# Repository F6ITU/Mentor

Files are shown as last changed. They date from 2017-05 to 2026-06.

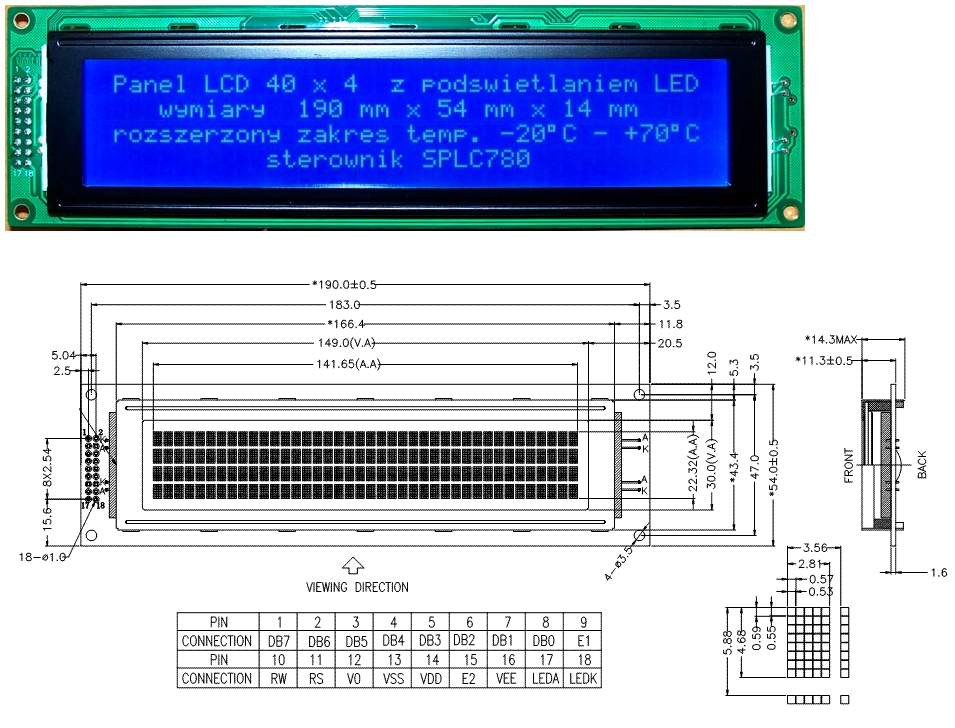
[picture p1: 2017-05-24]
Datasheet/4x40 display pinout.PNG

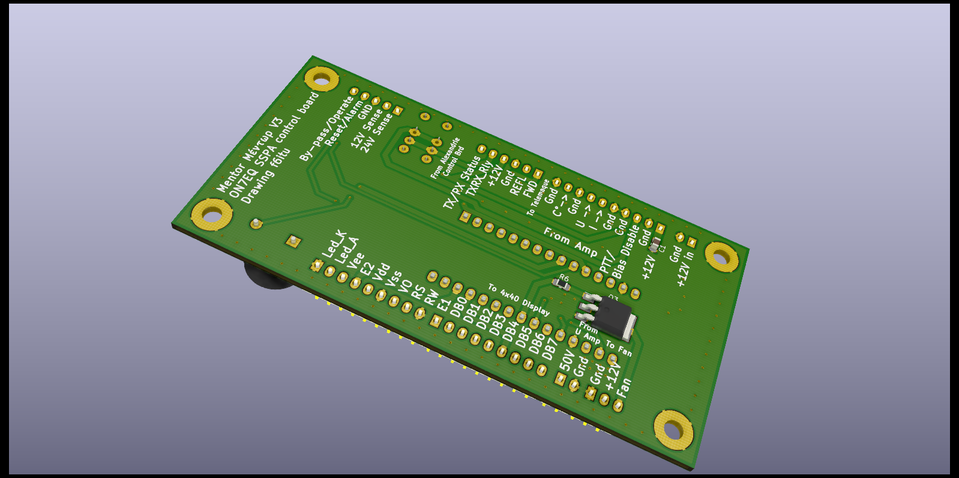
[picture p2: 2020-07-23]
pictures/Mentor_Dwh.png

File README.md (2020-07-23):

# Mentor

Kicad files

An Arduino based SSPA display controler for HPSDR/Hermes familly
This module controls 
- voltage
- current
- temperature
- VSWR/PWR
- cooling fan
- 4x40 lcd display
and shuts down the Bias current while beeping in case of dificulties

This board and the associated firmware have been developped by ON7EQ. 

http://www.qsl.net/on7eq/projects/arduino_sspa.htm

Some code modifications have been made by John Melton for 
the Hermes familly.

The design of this board uses the generic output names
used by all Hermes/Angelia boards and could directly be plugged 
on the Alexandrie control board

So far, NO SSPA and NO Reflectometer/Refl-fwd coupler have been
designed. A multipurpose 33dB Tandem Match coupler
is under development (for both VSWR/PWR measurement and 
predistorsion -aka "pure signal"- sampling)

Board's dimensions are oversized to fit the 5x10 and 10x10cm 
size of all board of the Hermes project under Kicad: 

AlexI2C

Alexandrie 

Alexiares_Coax_Out

Alexiares_HPF

Alexiares_LPF

Mentor(this one)

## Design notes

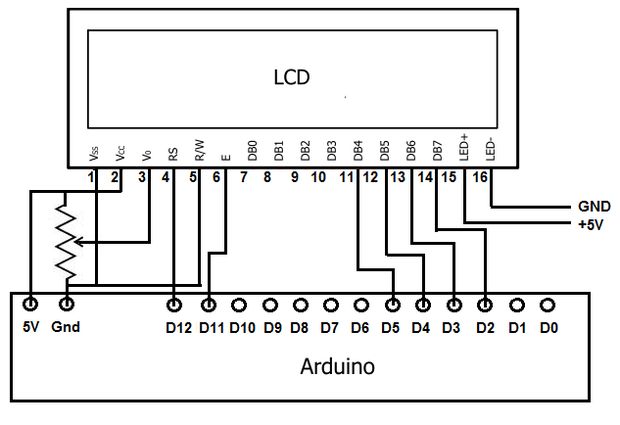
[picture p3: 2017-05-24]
Datasheet/lcd pinout.jpg

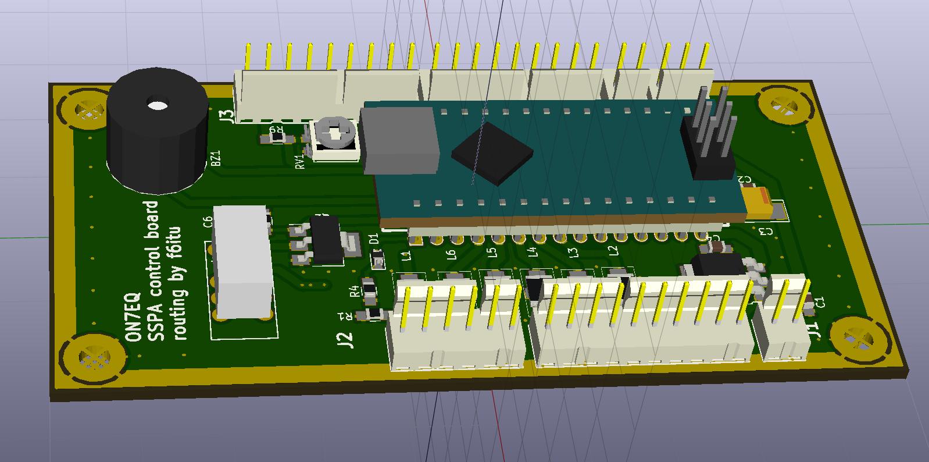
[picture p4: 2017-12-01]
Mentor_up.jpg

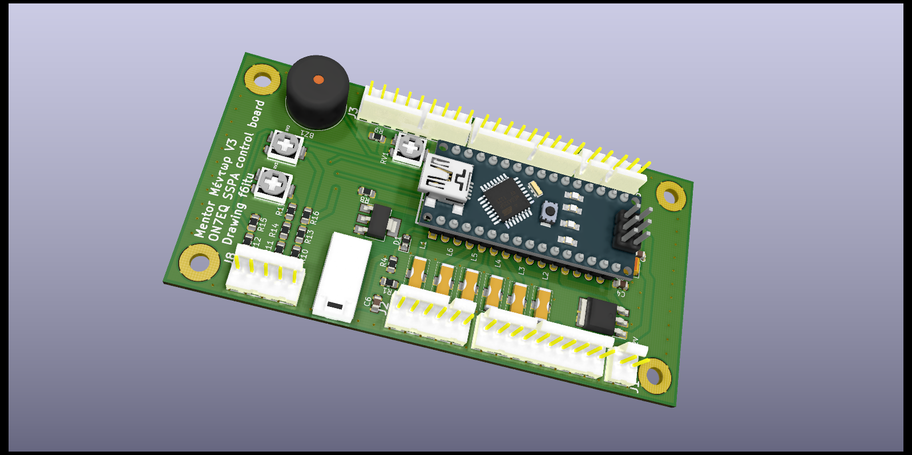
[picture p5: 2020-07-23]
pictures/Mentor_Up.png

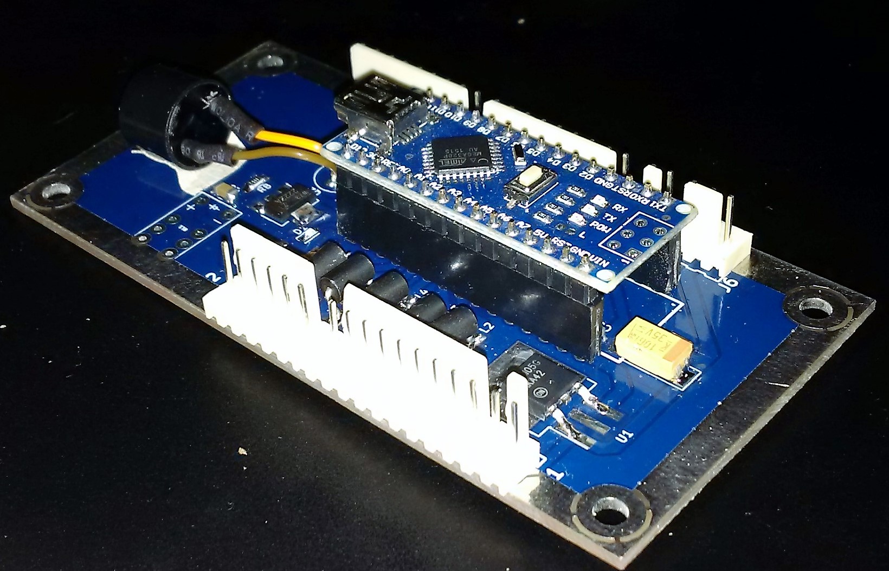
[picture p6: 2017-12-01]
Mentor_pcb.jpg

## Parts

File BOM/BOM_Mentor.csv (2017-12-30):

Component Count: | 37
Ref | Value | Footprint | Datasheet | Manufacturer | Vendor
BZ1 | Buzzer | Buzzers_Beepers:Buzzer_12x9.5RM7.6
C1 | 100n | Capacitors_SMD:C_0805_HandSoldering
C2 | 10u | Capacitors_Tantalum_SMD:CP_Tantalum_Case-C_EIA-6032-28_Hand
C3 | 100n | Capacitors_SMD:C_0805_HandSoldering
C4 | 100n | Capacitors_SMD:C_0805_HandSoldering
C5 | 100n | Capacitors_SMD:C_0805_HandSoldering
C6 | 100n | Capacitors_SMD:C_0805_HandSoldering
D1 | LED | Diodes_SMD:D_0805 | LED
J1 | CONN_01X02 | conn_kk100:kk100_22-23-2021
J2 | CONN_01X06 | conn_kk100:kk100_22-23-2061
J3 | CONN_01X09 | conn_kk100:kk100_22-23-2091
J4 | CONN_01X10 | conn_kk100:kk100_22-23-2101
J5 | CONN_01X02 | conn_kk100:kk100_22-23-2021
J6 | CONN_01X03 | conn_kk100:kk100_22-23-2031
J7 | CONN_01X09 | conn_kk100:kk100_22-23-2091
L1 | L_cap | Ferrite_LC_NFM41P:Ferrite_LC_NFM41P
L2 | L_cap | Ferrite_LC_NFM41P:Ferrite_LC_NFM41P
L3 | L_cap | Ferrite_LC_NFM41P:Ferrite_LC_NFM41P
L4 | L_cap | Ferrite_LC_NFM41P:Ferrite_LC_NFM41P
L5 | L_cap | Ferrite_LC_NFM41P:Ferrite_LC_NFM41P
L6 | L_cap | Ferrite_LC_NFM41P:Ferrite_LC_NFM41P
Q1 | PZT2222A | TO_SOT_Packages_SMD:SOT-223
Q2 | PZT2222A | TO_SOT_Packages_SMD:SOT-223
Q3 | IRFR3303 | TO_SOT_Packages_SMD:TO-252-3_TabPin2
R1 | 10k | Resistors_SMD:R_0805_HandSoldering
R2 | 0R | Resistors_SMD:R_0805_HandSoldering
R3 | 0R | Resistors_SMD:R_0805_HandSoldering
R4 | 330R | Resistors_SMD:R_0805_HandSoldering
R5 | 1k | Resistors_SMD:R_0805_HandSoldering
R6 | 1k | Resistors_SMD:R_0805_HandSoldering
R7 | 2k2 | Resistors_SMD:R_0805_HandSoldering
R8 | 10k | Resistors_SMD:R_0805_HandSoldering
R9 | 100R | Resistors_SMD:R_0805_HandSoldering
RL1 | EC2-12NU | 2_Form_C_Relay:THT_2_formC
RV1 | 10k | Trimmer_3314G1_Handsoldering:Trimmer_3314G1_Handsoldering
U1 | KA78M05_TO252 | TO_SOT_Packages_SMD:TO-252-3_TabPin2
U2 | Arduino_Nano | arduino_nano:arduino_nano

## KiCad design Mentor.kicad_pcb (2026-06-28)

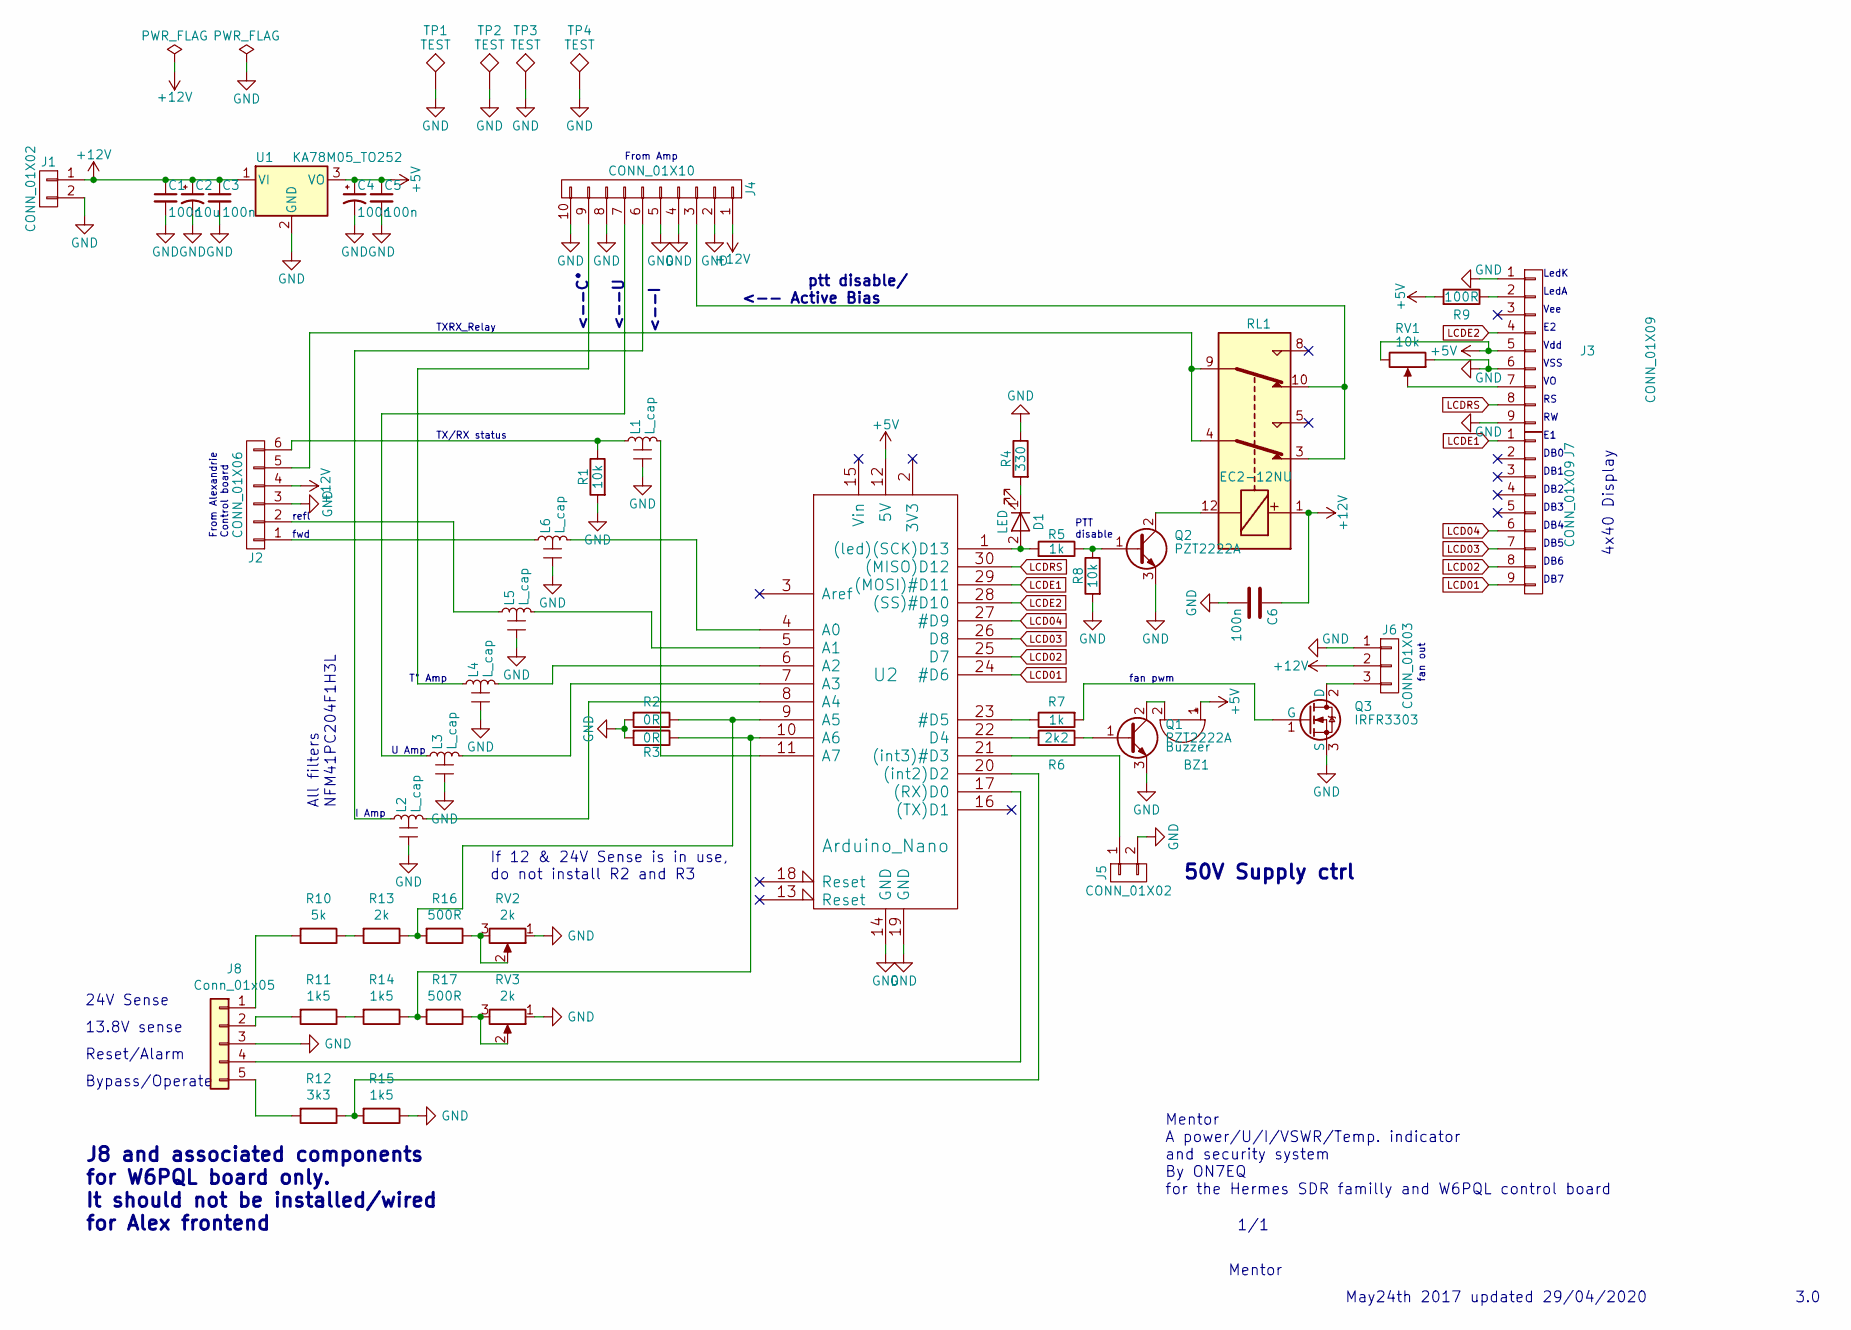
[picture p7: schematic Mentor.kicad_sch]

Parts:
BZ1: Buzzer; Buzzer_12x9.5RM7.6
C1, C3, C4, C5, C6: 100n; C_0805_2012Metric_Pad1.15x1.40mm_HandSolder
C2: 10u; CP_EIA-6032-28_Kemet-C_Pad2.25x2.35mm_HandSolder
D1: LED; D_0805_2012Metric_Pad1.15x1.40mm_HandSolder
J1, J5: CONN_01X02; kk100_22-23-2021
J2: CONN_01X06; kk100_22-23-2061
J3, J7: CONN_01X09; kk100_22-23-2091
J4: CONN_01X10; kk100_22-23-2101
J6: CONN_01X03; kk100_22-23-2031
J8: Conn_01x05; kk100_22-23-2051
L1, L2, L3, L4, L5, L6: L_cap; Ferrite_LC_NFM41P
Q1, Q2: PZT2222A; SOT-223
Q3: IRFR3303; TO-252-3_TabPin2
R1, R8: 10k; R_0805_2012Metric_Pad1.15x1.40mm_HandSolder
R2, R3: 0R; R_0805_2012Metric_Pad1.15x1.40mm_HandSolder
R4: 330; R_0805_2012Metric_Pad1.15x1.40mm_HandSolder
R5, R6: 1k; R_0805_2012Metric_Pad1.15x1.40mm_HandSolder
R7: 2k2; R_0805_2012Metric_Pad1.15x1.40mm_HandSolder
R9: 100R; R_0805_2012Metric_Pad1.15x1.40mm_HandSolder
R10: 5k; R_0805_2012Metric_Pad1.15x1.40mm_HandSolder
R11, R14, R15: 1k5; R_0805_2012Metric_Pad1.15x1.40mm_HandSolder
R12: 3k3; R_0805_2012Metric_Pad1.15x1.40mm_HandSolder
R13: 2k; R_0805_2012Metric_Pad1.15x1.40mm_HandSolder
R16, R17: 500R; R_0805_2012Metric_Pad1.15x1.40mm_HandSolder
RL1: EC2-12NU; THT_2_formC
RV1: 10k; Trimmer_3314G1_Handsoldering
RV2, RV3: 2k; Trimmer_3314G1_Handsoldering
TP1, TP2, TP3, TP4: TEST; MountingHole_3.5mm_Pad
U1: KA78M05_TO252; TO-252-3_TabPin2
U2: Arduino_Nano; arduino_nano

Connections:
+5V: BZ1.1 (-), C4.1, C5.1, J3.5, R9.2, RV1.3, U1.3 (VO), U2.12 (5V)
+12V: C1.1, C2.1, C3.1, C6.1, J1.1, J2.4, J4.1, J6.2, RL1.1, U1.1 (VI)
GND: C1.2, C2.2, C3.2, C4.2, C5.2, C6.2, J1.2, J2.3, J3.1, J3.6, J3.9, J4.2, J4.4, J4.5, J4.8, J4.10, J5.2, J6.1, J8.3, L1.2, L2.2, L3.2, L4.2, L5.2, L6.2, Q1.3 (E), Q2.3 (E), Q3.3 (S), R1.2, R2.2, R3.2, R4.1, R8.2, R15.1, RV1.1, RV2.1, RV3.1, TP1.1, TP2.1, TP3.1, TP4.1, U1.2 (GND), U2.14 (GND), U2.19 (GND)
LCD01: J7.9, U2.24 (#D6)
LCD02: J7.8, U2.25 (D7)
LCD03: J7.7, U2.26 (D8)
LCD04: J7.6, U2.27 (#D9)
LCDE1: J7.1, U2.29 ((MOSI)#D11)
LCDE2: J3.4, U2.28 ((SS)#D10)
LCDRS: J3.8, U2.30 ((MISO)D12)
unnamed: BZ1.2 (+), Q1.2 (C)
unnamed: D1.1 (K), R4.2
unnamed: D1.2 (A), R5.2, U2.1 ((led)(SCK)D13)
unnamed: J2.1, L6.1
unnamed: J2.2, L5.1
unnamed: J2.5, RL1.4, RL1.9
unnamed: J2.6, L1.1, R1.1
unnamed: J3.2, R9.1
unnamed: J3.7, RV1.2
unnamed: J4.3, RL1.3, RL1.10
unnamed: J4.6, L2.1
unnamed: J4.7, L3.1
unnamed: J4.9, L4.1
unnamed: J5.1, U2.21 ((int3)#D3)
unnamed: J6.3, Q3.2 (D)
unnamed: J8.1, R10.2
unnamed: J8.2, R11.2
unnamed: J8.4, U2.17 ((RX)D0)
unnamed: J8.5, R12.2
unnamed: L1.3, U2.11 (A7)
unnamed: L2.3, U2.8 (A4)
unnamed: L3.3, U2.7 (A3)
unnamed: L4.3, U2.6 (A2)
unnamed: L5.3, U2.5 (A1)
unnamed: L6.3, U2.4 (A0)
unnamed: Q1.1 (B), R7.1
unnamed: Q2.1 (B), R5.1, R8.1
unnamed: Q2.2 (C), RL1.12
unnamed: Q3.1 (G), R6.2
unnamed: R6.1, U2.23 (#D5)
unnamed: R7.2, U2.22 (D4)
unnamed: R10.1, R13.2
unnamed: R11.1, R14.2
unnamed: R12.1, R15.2, U2.20 ((int2)D2)
unnamed: R2.1, R13.1, R16.2, U2.9 (A5)
unnamed: R3.1, R14.1, R17.2, U2.10 (A6)
unnamed: R16.1, RV2.2, RV2.3
unnamed: R17.1, RV3.2, RV3.3

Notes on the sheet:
50V Supply ctrl
ptt disable/ <-- Active Bias
TXRX_Relay
24V Sense
<--I
T° Amp
Bypass/Operate
From Amp
DB6
<--U
Mentor A power/U/I/VSWR/Temp. indicator and security system By ON7EQ for the Hermes SDR familly and W6PQL control board
DB0
DB4
All filters NFM41PC204F1H3L
4x40 Display
DB5
May24th 2017 updated 29/04/2020
13.8V sense
3.0
Vdd
fwd
DB3
LedA
DB1
fan pwm
I Amp
J8 and associated components for W6PQL board only. It should not be installed/wired for Alex frontend
fan out
DB7
Reset/Alarm
From Alexandrie Control board
VSS
LedK
DB2
If 12 & 24V Sense is in use, do not install R2 and R3
U Amp
1/1
Vee
<--C°
TX/RX status

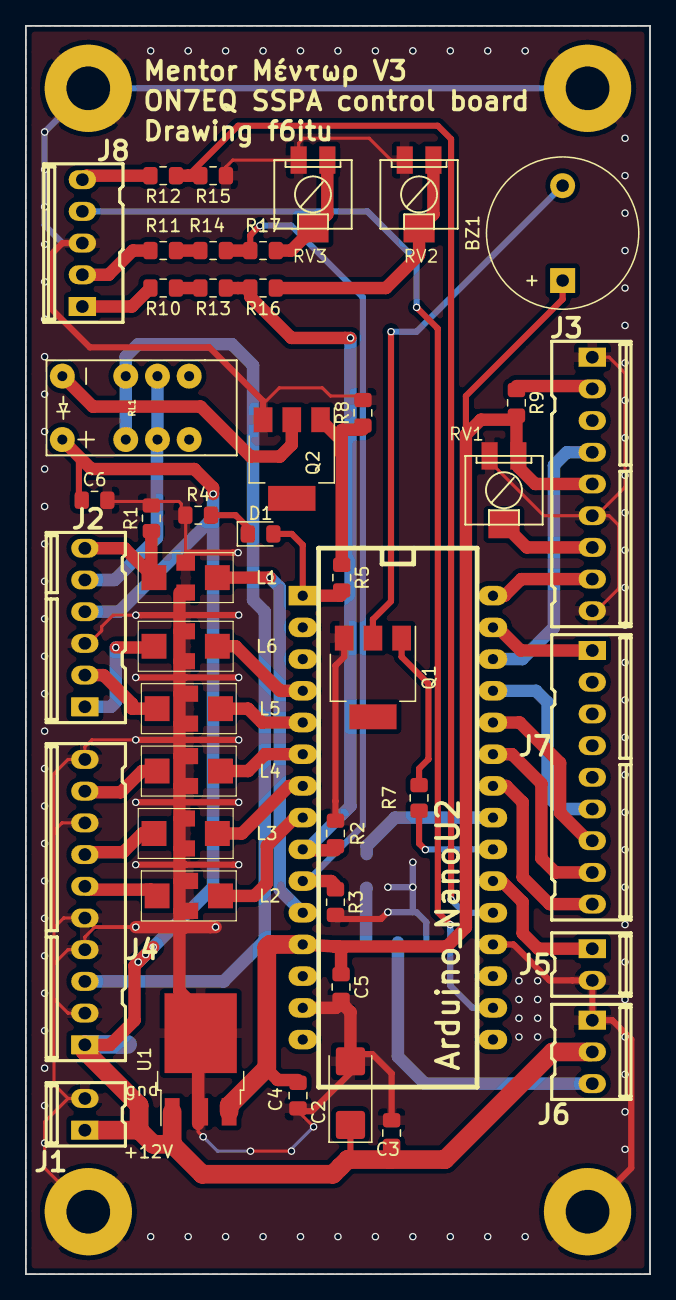
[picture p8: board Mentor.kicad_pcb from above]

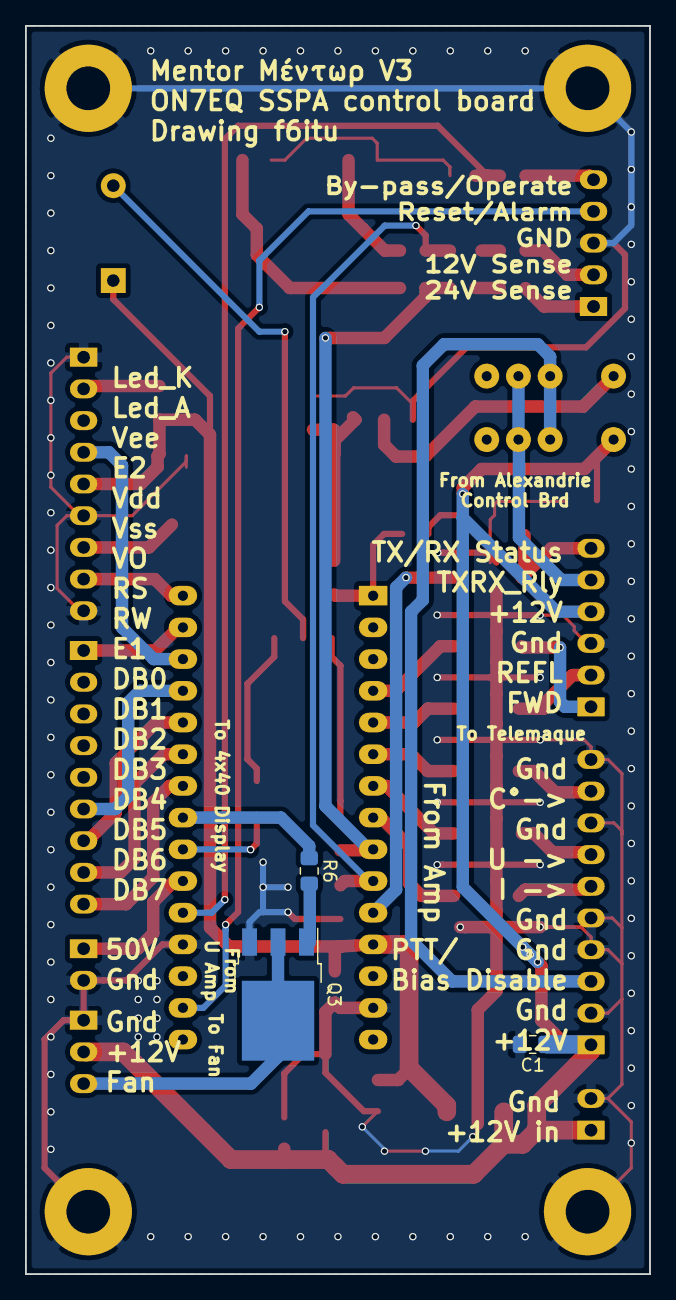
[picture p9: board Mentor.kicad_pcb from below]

Board: 2 copper layers, 50.0 x 100.0 mm, 52 parts (3 on the bottom side), 48 nets.

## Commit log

2017-05-24 Mentor display board for HPSDR first commit
    [Alexandrite.kicad_pcb, Alexandrite.sch]
2017-05-24 pdf view of Mentor's schematic
2017-05-24 Mentor Schematic, V1.0
    [Mentor.kicad_pcb, Mentor.sch]
2017-05-24 New schematic pdf file
2017-05-25 final schematic drawing
    [Mentor.sch]
2017-05-27 Mentor pcb routed, minor errors fixed
    [Mentor.sch]
2017-05-29 RTM, silmask to do
    [Mentor.kicad_pcb, Mentor.sch]
2017-06-12 carte de control V1.0
    [Mentor.dsn, Mentor.kicad_pcb, Mentor.sch]
2017-07-29 add a THT relay, cleaning silk, shielding mask zone added
    [Mentor.kicad_pcb, Mentor.sch]
2017-11-01 RTM 1
    [Mentor.kicad_pcb, Mentor.sch]
2017-11-02 Readme cleaning, add 2 3D pictures
    [Mentor.kicad_pcb]
2017-11-27 new ferrite footprint, minor routing changes
    [Mentor.kicad_pcb, Mentor.sch]
2017-12-01 RTM2, via, prototype picture, gerber added
    [Mentor-B.Cu.gbl, Mentor-B.Mask.gbs, Mentor-B.SilkS.gbo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]
2017-12-01 Silkmask comment added
    [Mentor.kicad_pcb]
2017-12-01 buzzer changed
    [Mentor-B.Cu.gbl, Mentor-B.Mask.gbs, Mentor-B.SilkS.gbo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]
2017-12-30 minor changes, Gerber and BOM added
    [Mentor.csv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]
2018-07-23 Mentor V2 RTM
    [Mentor.kicad_pcb, Mentor.sch]
2020-07-23 Mentor V3.0 W6PQL compatible
    [BOM_Mentor.csv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]
2026-06-28 new schematic for w6pql compatibility
    [Mentor.kicad_pcb, Mentor.kicad_sch]
